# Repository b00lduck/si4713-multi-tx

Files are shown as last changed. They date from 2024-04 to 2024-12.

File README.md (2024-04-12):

# 4-CH FM modulator with ESP32 and si4713

This project is a FM modulator with 4 channels, consisting of four si4713 FM transmitters controlled by an ESP32.

The setup is used in an installation where four audio sources are modulated to FM and injected into a FM distribution system. The four outputs are connected to a 4-channel RF combiner, which is then connected to an antenna amplifier along with other RF sources i.e. aerials.

Programming is done with one rotary encoder and four OLED displays.

For a detailed schematic see the kicad project in the `kicad` folder.

3d printed parts can be found in the `openscad` folder.

## Hardware

- Stripboard
- ESP32
- 4x si4713 FM transmitter
- 4x SSD1306 OLED display
- Rotary encoder
- 8x cinch connector
- 4x BNC connector
- 19" rack case with custom front panel
- 3d printed back panel

The ESP32 is connected to the si4713 FM transmitters via I2C and to the OLED displays via two I2C buses.
The rotary encoder is connected to the ESP32 via three GPIO pins, two for the encoder and one for the push button.

## Software

The software is written in C++ using the Arduino framework and PlatformIO.

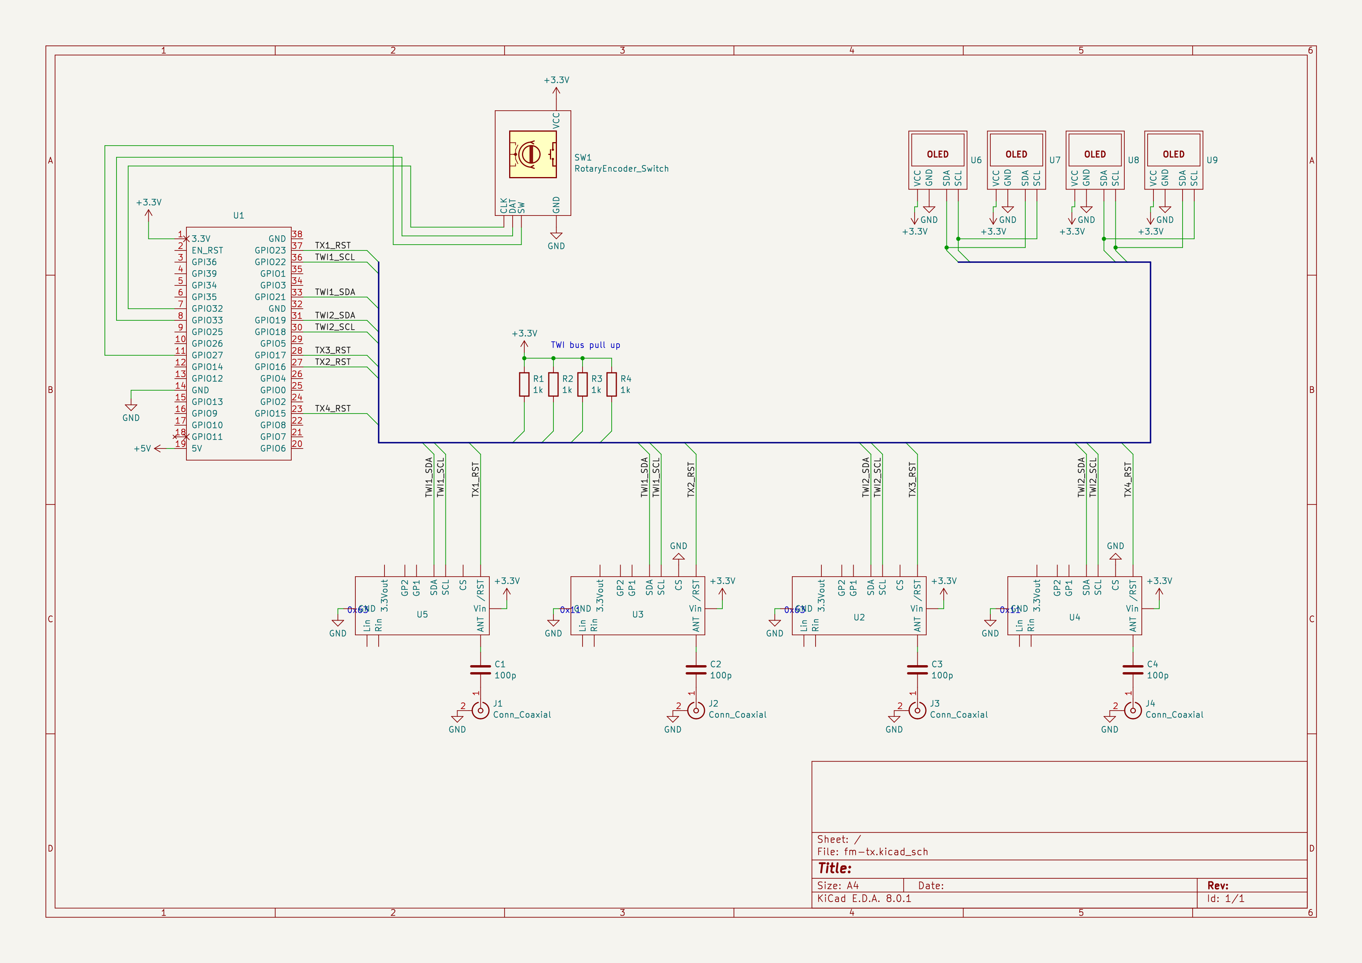
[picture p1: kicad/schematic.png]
Schematic


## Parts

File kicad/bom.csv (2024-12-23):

Designator | Comment | Footprint | LCSC Part Number
C1 | 100n | Capacitor_SMD:C_0805_2012Metric | C28233
C4,C5,C6,C7,C8,C9,C10,C11,C12,C13,C14,C15 | 100p | Capacitor_SMD:C_0402_1005Metric | C1546
R1 | 4700 | Resistor_SMD:R_0805_2012Metric | C17673
R2 | 1200 | Resistor_SMD:R_0603_1608Metric | C22765
R3 | 540 | Resistor_SMD:R_0603_1608Metric | C23204
R4,R6,R7,R8,R10 | 25 | Resistor_SMD:R_0805_2012Metric | C2828760
R5,R9 | 50 | Resistor_SMD:R_0402_1005Metric | C3015747

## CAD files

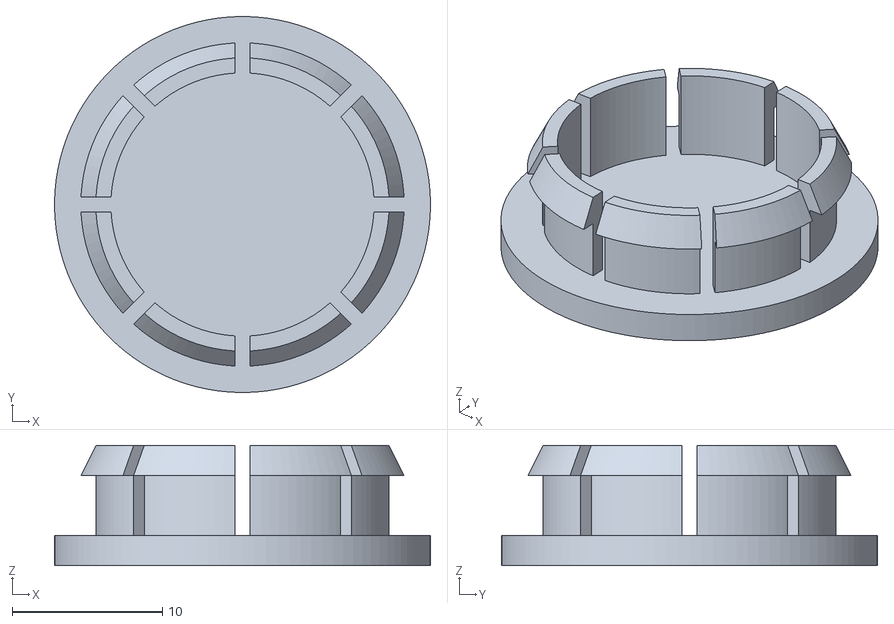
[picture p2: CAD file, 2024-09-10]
openscad/usb_cover.stl
25.0 x 25.0 x 8.00

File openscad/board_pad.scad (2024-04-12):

w = 159;
h = 82;
t = 0.4;
$fn = 100;

dsx = 2.54 * 60;
dsy = 2.54 * 30;

sh = 4 + t;

translate([-w/2,-h/2,0]) cube([w,h,t]);


translate([-dsx/2,-dsy/2,0]) stud();
translate([-dsx/2,dsy/2,0]) stud();
translate([0,dsy/2,0]) stud();
translate([2.54*4,-dsy/2,0]) stud();
translate([-2.54*8,-dsy/2,0]) stud();
translate([dsx/2,dsy/2,0]) stud();
translate([dsx/2,-dsy/2,0]) stud();


module stud() {
    
    difference() {
        cylinder(sh,3,3);
        cylinder(sh,1,1);
    }    
}

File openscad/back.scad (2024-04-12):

$fn = 100;

width = 437;
height = 43;
thickness = 2;

half1Width = 213;
half2Width = width - half1Width;

distPlate = 3;

connectorWidth = 10;
connectorDepth = 20;
connectorHeight = height - (distPlate*2);

holedistY = 35;
holedistX = 428;

half1();

module half1() {
    // left
    difference() {
        half(half1Width);
        translate([half1Width-(connectorWidth/2),height,10+thickness]) rotate([90,0,0]) cylinder(5,0.9,0.9);
        translate([half1Width-(connectorWidth/2),5,10+thickness]) rotate([90,0,0]) cylinder(5,0.9,0.9);

        translate([30,height/2,0]) cylinder(10,4,4);

        // bnc
        for(x=[0:25:80]) {
            translate([x+100,height/2,0]) cylinder(10,5,5);
        }
    }
}

module half2() {
    // right
    translate([0,0,0]) 
    difference() {
        rotate([0,0,0]) half(half2Width);

        // cinch
        for(y=[-7,7])
        for(x=[0:20:60]) {
            translate([x+100,height/2+y,0]) cylinder(10,4,4);
        }

    }
}

module half(w) {
    difference() {
        union() {
            cube([w, height, thickness]);
            translate([25,distPlate,0]) cube([w-30, 4, 7]);
            translate([25,height-4-distPlate,0]) cube([w-30, 4, 7]);
            translate([w - connectorWidth,distPlate,0]) cube([connectorWidth, connectorHeight, connectorDepth]);
        }
        translate([w-20,height-10,connectorDepth/2]) rotate([0,90,0]) cylinder(40,2,2);
        translate([w-20,10,connectorDepth/2]) rotate([0,90,0]) cylinder(40,2,2);

        translate([4,(height-holedistY)/2,0]) rotate([0,0,0]) cylinder(40,2,2);
        translate([4,(height+holedistY)/2,0]) rotate([0,0,0]) cylinder(40,2,2);        
    }
    
}

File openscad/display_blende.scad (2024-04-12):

dispW = 25;
dispH = 13.7;

dispYoff = 0;

holeW = 110;
holeH = 23;

dist = 2.54 * 10;

kragenOut = 7;
thicknessOut = 1;

kragenIn = 2;
thicknessIn = 1;
stegWidth = 2;


borderW = holeW + kragenOut;
borderH = holeH + kragenOut;

depth = 3;
    //font();
difference() {
    main();
    font();
}




module font() {
    startx = -43;
    font="Bahnschrift";
    translate([0,-0.5,0.3]) linear_extrude(0.2) {
        translate([startx,9.5,0]) text("CH 1", size=4, font=font);
        translate([startx + dist,9.5,0]) text("CH 2", size=4, font=font);
        translate([startx + dist * 2,9.5,0]) text("CH 3", size=4, font=font);
        translate([startx + dist * 3,9.5,0]) text("CH 4", size=4,font=font);
    }
}



module main() {
    difference() {
        union() {
            cube([borderW, borderH, thicknessOut], true);
            translate([0,0,-2.5]) cube([102, 13, 5], true);
            difference() {
                translate([0,0,-depth/2]) cube([holeW, holeH, depth], true);        
                translate([0,16,-3]) cube([102,20,3],true);
            }    }
        translate([-dist/2-+dispW,0,0]) displayCut();
    }
}

module displayCut() {
    for(i=[0:1:3]) {
        translate([-0.7 + i * dist, 0, 0]) cube([dispW, dispH, 50], true);
    }
}

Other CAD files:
openscad/usb_cover.scad

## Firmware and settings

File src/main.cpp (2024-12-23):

#include <Arduino.h>
#include "Transmitter.h"
#include "config.h"
#if BOARD_VERSION == 1
  #include "OledDisplay.h"
#elif BOARD_VERSION == 2
  #include "LcdDisplay.h"
#endif
#include "AiEsp32RotaryEncoder.h"
#include "State.h"

AiEsp32RotaryEncoder rotaryEncoder = AiEsp32RotaryEncoder(ROTARY_A_PIN,ROTARY_B_PIN,ROTARY_BUTTON_PIN,-1,4);

State state;

TwoWire wireA = TwoWire(0);
TwoWire wireB = TwoWire(1);

Transmitter tx[] = {
 Transmitter(&wireA,TX1_ADDR,TX1_RESET_PIN),
 Transmitter(&wireA,TX2_ADDR,TX2_RESET_PIN),
 Transmitter(&wireB,TX3_ADDR,TX3_RESET_PIN),
 Transmitter(&wireB,TX4_ADDR,TX4_RESET_PIN),
};

#define NUM_TX (sizeof(tx)/sizeof(tx[0]))
#if BOARD_VERSION == 1
 #define NUM_DISPLAYS NUM_TX
#elif BOARD_VERSION == 2
 #define NUM_DISPLAYS 1
#endif

#if BOARD_VERSION == 1
  OledDisplay display[NUM_TX] = {
    OledDisplay(&wireA, 0x3C),
    OledDisplay(&wireA, 0x3D),
    OledDisplay(&wireB, 0x3C),
    OledDisplay(&wireB, 0x3D),
  };
#elif BOARD_VERSION == 2
  LcdDisplay display[NUM_DISPLAYS] {
  LcdDisplay(&wireA, 0x27)
  };
#endif

void IRAM_ATTR readEncoderISR() {
    rotaryEncoder.readEncoder_ISR();
}

uint8_t uiMode = 0;
uint8_t selectedChannel = 0;
uint8_t selectedDigit = 0;

uint32_t screenSaverTimer = millis();
bool screenSaver = false;

void enableScreenSaver() {
  for (int i = 0; i < NUM_DISPLAYS; i++) {
    display[i].screenSaver = true;
    screenSaver = true;
    uiMode = 0;
  }
}

void disableScreenSaver() {
  screenSaverTimer = millis();
  for (int i = 0; i < NUM_DISPLAYS; i++) {
    display[i].screenSaver = false;
    screenSaver = false;
  }
}

void resetScreenSaver() {
  screenSaverTimer = millis();
}

void setup() {

  Serial.begin(9600);

  Serial.println("initializing TWI...");
  wireA.begin(TWI1_SDA, TWI1_SCL, 250000);
  wireB.begin(TWI2_SDA, TWI2_SCL, 250000);

  Serial.print("initializing displays... ");
  for (int i = 0; i < NUM_DISPLAYS; i++) {
    display[i].init();
  }

  #if BOARD_VERSION == 2
    display[0].showLoadingProgress(1, "load settings");
  #endif

  state.load(NUM_TX);

  Serial.print("\ninitializing transmitters... ");
  for (int i = 0; i < NUM_TX; i++) {
    Serial.printf("TX%d ", i+1);
    tx[i].init();
    tx[i].configure(&state.channelState[i]);
    tx[i].readStatus();
    #if BOARD_VERSION == 2
      display[0].showLoadingProgress(2+i, "Init TX");
    #endif
  }
  for(int i = 0; i < 4; i++) {
    sleep(1);
    #if BOARD_VERSION == 2
      display[0].showLoadingProgress(6+i, "Init TX");
    #endif
  }
  for (int i = 0; i < NUM_TX; i++) {
    tx[i].configure(&state.channelState[i]);
    #if BOARD_VERSION == 1
      display[i].show(&state.channelState[i], tx[i].getLevel());
    #endif
    #if BOARD_VERSION == 2
      display[0].showLoadingProgress(10+i*2, "Init TX");
    #endif
    tx[i].readStatus();
    sleep(1);
    #if BOARD_VERSION == 2
      display[0].showLoadingProgress(10+i*2+1, "Init TX");
    #endif
    sleep(1);  
  }

  #if BOARD_VERSION == 2
    display[0].showLoadingProgress(18, "Init Encoder");
  #endif
  
  Serial.println("\ninitializing rotary encoder...");
  rotaryEncoder.begin();
  rotaryEncoder.setAcceleration(20);
  rotaryEncoder.setup(readEncoderISR);

  Serial.println("initializing done.");

  resetScreenSaver();

  #if BOARD_VERSION == 2
    usleep(300000);
    display[0].clear();
    display[0].selectCharset(1);
  #endif
}

void loop() {

  uint32_t inactivity = millis() - screenSaverTimer;
  if (inactivity > 10000) {
    enableScreenSaver();
  }

    if (rotaryEncoder.encoderChanged()) {
      Serial.printf("Selected channel: %d, Encoder value %d\n", selectedChannel, rotaryEncoder.readEncoder());
      if (screenSaver) {
        disableScreenSaver();
      } else {
        resetScreenSaver();
        switch(uiMode) {
          case 0:
            break;
          case 1:
            break;
          case 2:
            Serial.printf("Selected value %d\n", rotaryEncoder.readEncoder());
            state.channelState[selectedChannel].freq = rotaryEncoder.readEncoder() * FREQENC_DIVISOR;
            Serial.printf("New freq: %d\n", state.channelState[selectedChannel].freq);
            tx[selectedChannel].configure(&state.channelState[selectedChannel]);
            break;
          case 3:
            Serial.printf("Selected value %d\n", rotaryEncoder.readEncoder());
            state.channelState[selectedChannel].ps[selectedDigit] = rotaryEncoder.readEncoder();
            tx[selectedChannel].configure(&state.channelState[selectedChannel]);
            break;
          case 4:
            Serial.printf("Selected value %d\n", rotaryEncoder.readEncoder());
            state.channelState[selectedChannel].enabled = !state.channelState[selectedChannel].enabled;
            tx[selectedChannel].configure(&state.channelState[selectedChannel]);
        }
      }
    }

    if (rotaryEncoder.isEncoderButtonClicked()) {
      if (screenSaver) {
        disableScreenSaver();
      } else {
        resetScreenSaver();
        switch(uiMode) {
          case 0:
            Serial.println("UI mode 1 - Channel selection");
            uiMode = 1;
            rotaryEncoder.setAcceleration(0);
            rotaryEncoder.setBoundaries(0, NUM_TX-1, false);
            rotaryEncoder.setEncoderValue(0);
            break;
          case 1:
            selectedChannel = rotaryEncoder.readEncoder();
            Serial.printf("UI mode 2 - Frequency selection for CH%d\n", selectedChannel);
            uiMode = 2;
            rotaryEncoder.setAcceleration(250);
            rotaryEncoder.setBoundaries(FREQENC_BOUND_LOW,FREQENC_BOUND_HIGH,false);
            rotaryEncoder.setEncoderValue(state.channelState[selectedChannel].freq / FREQENC_DIVISOR);
            break;
          case 2:
            Serial.println("UI mode 3 - Name selection");
            uiMode = 3;
            selectedDigit = 0;
            Serial.printf("Selected digit %d\n", selectedDigit);
            rotaryEncoder.setAcceleration(50);
            rotaryEncoder.setBoundaries(32,90,false);
            rotaryEncoder.setEncoderValue(state.channelState[selectedChannel].ps[selectedDigit]);
            break;
          case 3:
            if (selectedDigit == (PS_MAX_LENGTH-1)) {
              Serial.println("UI mode 4 - Enable/Disable TX");
              uiMode = 4;
              rotaryEncoder.setAcceleration(0);
              rotaryEncoder.setBoundaries(0,1,true);
              rotaryEncoder.setEncoderValue(state.channelState[selectedChannel].enabled);
              #if BOARD_VERSION == 1
                display[selectedChannel].invertPiDigit(0);
              #endif
            } else {
              selectedDigit++;
              Serial.printf("Selected digit %d\n", selectedDigit);
              rotaryEncoder.setEncoderValue(state.channelState[selectedChannel].ps[selectedDigit]);
            }
            break;
          case 4:
            state.channelState[selectedChannel].save();
            tx[selectedChannel].configure(&state.channelState[selectedChannel]);
            uiMode = 0;
        }    
      }
    }

    #if BOARD_VERSION == 1
      for (int i = 0; i < NUM_DISPLAYS; i++) {
        switch (uiMode) {
          case 0:
            display[i].invertAll(false);
            display[i].invertMhz(false);
            break;
          case 1:
            if (i == rotaryEncoder.readEncoder()) {
              display[i].invertAll(true);
            } else {
              display[i].invertAll(false);
            }
            break;
          case 2:
            display[i].invertAll(false);
            if (i == selectedChannel) {
              display[i].invertMhz(true);
            } else {
              display[i].invertMhz(false);
            }
            break;
          case 3:
            display[i].invertMhz(false);
            if (i == selectedChannel) {
              display[i].invertPiDigit(1<<selectedDigit);
            }
            break;
        }
        display[i].show(&state.channelState[i], tx[i].getLevel());   
      }
  #elif BOARD_VERSION == 2

        #define display display[0]

        uint8_t enc = rotaryEncoder.readEncoder();

        switch (uiMode) {
          case 0:
            for (int i = 0; i < NUM_TX; i++) {
              display.line[i]->visible(true);
              display.line[i]->show(&state.channelState[i], tx[i].getLevel());
            }
            break;
          case 1:
            for (int i = 0; i < NUM_TX; i++) {
              display.line[i]->visible(enc == i);
              display.line[i]->show(&state.channelState[enc], 0);              
            }           
            break;
          case 2:
            for (int i = 0; i < NUM_TX; i++) {
              display.line[i]->visible(selectedChannel == i);
              display.line[i]->blinkFrequency(selectedChannel == i);
              display.line[i]->show(&state.channelState[selectedChannel], 0);   
            }
              
            break;
          case 3:
            for (int i = 0; i < NUM_TX; i++) {
              display.line[i]->visible(selectedChannel == i);
              display.line[i]->blinkPiDigit(selectedDigit, selectedChannel == i);    
              display.line[i]->show(&state.channelState[selectedChannel], 0);   
            }
            break;
          case 4:
            for (int i = 0; i < NUM_TX; i++) {
              display.line[i]->visible(selectedChannel == i);
              display.line[i]->blinkEnabledFlag(selectedChannel == i);    
              display.line[i]->show(&state.channelState[selectedChannel], 0);   
            }
            break;

        }
        


  #endif


}

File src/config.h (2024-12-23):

#pragma once

#define MAX_NUM_TX 4
#define BOARD_VERSION 2

#if BOARD_VERSION == 1
    #define ROTARY_A_PIN 32
    #define ROTARY_B_PIN 33
#elif BOARD_VERSION == 2
    #define ROTARY_A_PIN 33
    #define ROTARY_B_PIN 32
#endif

#define ROTARY_BUTTON_PIN 27

#define TWI1_SDA 21
#define TWI1_SCL 22
#define TWI2_SDA 19
#define TWI2_SCL 18

#define TX1_ADDR 0x63
#define TX1_RESET_PIN 23
#define TX2_ADDR 0x11
#define TX2_RESET_PIN 16
#define TX3_ADDR 0x63
#define TX3_RESET_PIN 17   
#define TX4_ADDR 0x11
#define TX4_RESET_PIN 15

#define DEFAULT_FREQ 8750
#define TXPOWER 120  // max 120 
#define MIN_FREQ 8750
#define MAX_FREQ 10800

#define FREQENC_DIVISOR 5 // 10: Step 100kHz, 5: Step 50kHz
#define FREQENC_BOUND_LOW (MIN_FREQ / FREQENC_DIVISOR)
#define FREQENC_BOUND_HIGH (MAX_FREQ / FREQENC_DIVISOR)

#define PS_MAX_LENGTH 8

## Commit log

2024-04-12 update schematic
    [fm-tx.kicad_sch]
2024-09-10 Improved USB port cap
    [usb_cover.scad, usb_cover.stl]
2024-12-23 board v2
    [bom.csv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]
